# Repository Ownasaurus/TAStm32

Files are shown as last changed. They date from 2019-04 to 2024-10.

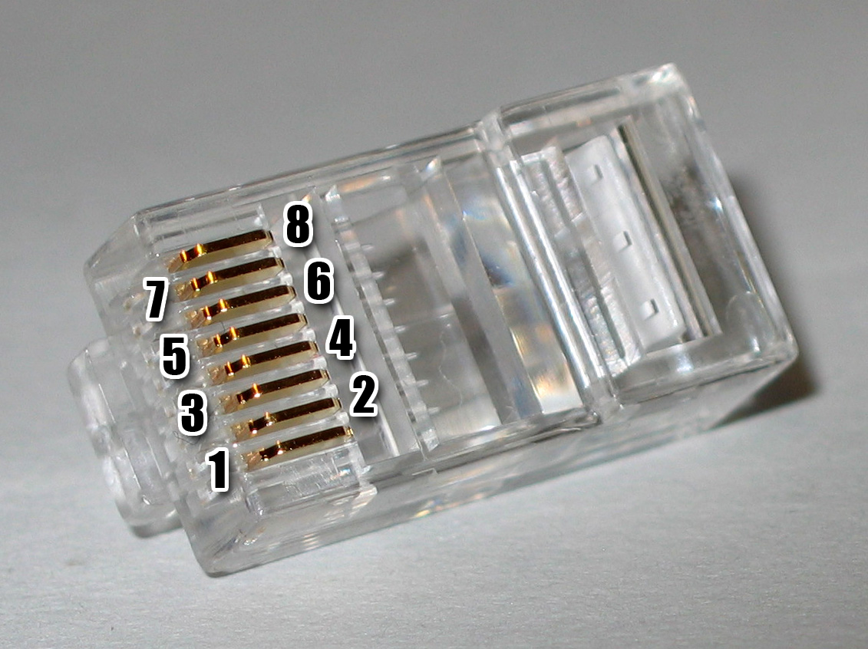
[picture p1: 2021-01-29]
Images/hardware_pinmaps/Rj45plug-8p8c.png

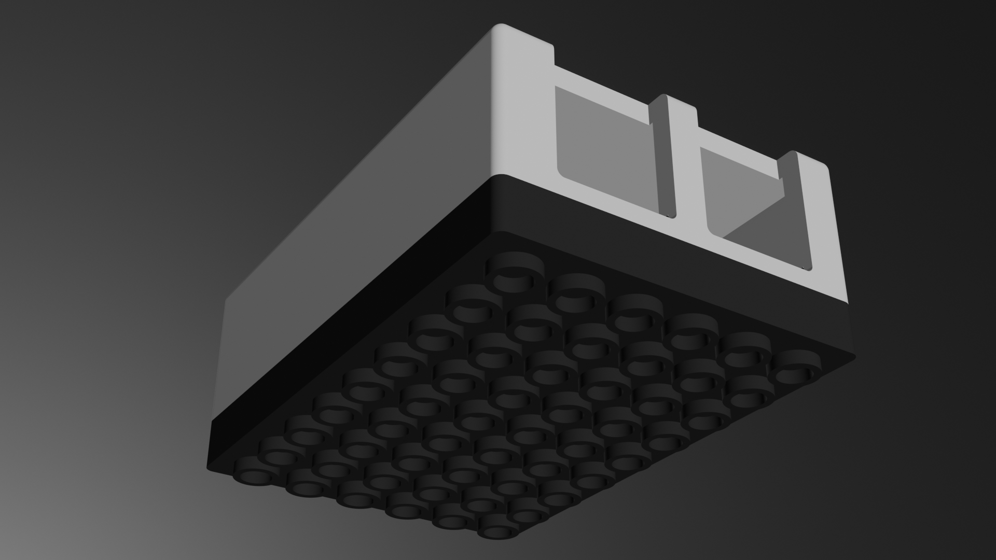
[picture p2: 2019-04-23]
Images/Render2.png

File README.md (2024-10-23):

# TAStm32
Please see the "Projects" section for an overview of the current status of this project!

Please see the "Wiki" section for the technical details of the serial communication protocol!

### Overview

This project aims to create an easy-to-use, multi-system TAS replay device to be used on actual consoles. The name of this project comes from the fact that it is powered by a STM32F4 microcontroller.

## How to use this device

#### Get Python3!
Install the [latest Python 3 release](https://www.python.org/downloads/)

(You may need to log out/log in to refresh the PATH variable)

Then install the required python modules with the following command:

    python3 -m pip install -r python/requirements.txt
    
#### Linux users -- make sure you are in the dialout and plugdev groups!

### Get the python scripts

Download the latest python scripts from https://github.com/Ownasaurus/TAStm32/releases/download/latest/python.zip

### Usage

Dumped TAS movies are available in the [TASBot projects repo](https://github.com/dwangoac/TASBot-Projects/tree/master/replayfiles)

[Scripts to dump your own TASes](https://github.com/dwangoac/TASBot-Projects/blob/master/Dump_Scripts/)

Once you've prepared a movie dump, use it with the TAStm32. Here is one example example is here:

    python3 tastm32.py --console snes --players 1,5 --dpcm --clock 14 --transition 2123 A --blank 1 smb3_agdq.r16m
    
Another option is to use python to run main.py, allowing you to utilize a GUI crated by Zayitskin. You can find more information on his repo here: https://github.com/Zayitskin/TAStm32GUI

## Upgrading firmware 

If it's the first time you're flashing it, short the "DFU" Pins (J13) while plugging tastm32 in.

#### Linux
    apt install dfu-util
OR the equivalent in your distribution. Then run:

    make v3 && make flash

Or :

    make v4 && make flash

#### Windows
1. Install STM32CubeProgrammer
1. Run the tastm32-dfu.py script to put the device in DFU mode (or if it's the first time you're flashing it, short the "DFU" Pins (J13) while plugging tastm32's USB cable into your computer).
1. Use the STM32CubeProgrammer software to flash the latest firmware. The latest firmware can always be found here: https://github.com/Ownasaurus/TAStm32/releases/download/latest/tastm32v3.hex
or
https://github.com/Ownasaurus/TAStm32/releases/download/latest/tastm32v4.hex

## Development (advanced users)

Do you want to fork the codebase and make your own tweaks? Here is some information that may help you.

### Compilation

#### Linux
    apt install gcc-arm-none-eabi binutils-arm-none-eabi libnewlib-arm-none-eabi
OR the equivalent in your distribution. Then run:

    make v3
    
Or : 

    make v4
    
Depending on if you have a v3 or v4 board. (v4 boards were released after July 2021)

#### Windows
1. Install Atollic TrueStudio
1. Right-click on the project > Build Configurations > Set Active, then click "Release v3" or "Release v4" depending on your board version. (v4s came out around July 2021)
1. Project > Build Project and check that the console shows no errors. The last line before "build finished" should be "arm-atollic-eabi-objcopy -O ihex TAStm32.elf TAStm32.hex".
1. Feel free to use the helper scripts "setenv.bat" and either "flashv3.bat" or "flashv4.bat" to assist in flashing firmware. These scripts will work if you have compiled using TrueStudio and if you have STM32CubeProgrammer installed.

### Special Thanks
#### rasteri (@rasteri) - Standalone USB playback, SNES multitap, v4 PCB, and more!
#### TheMas3212 (@TheMas3212) - Aided with all things python, designing the serial communication protocol, helping with PCB design, and debugging throughout the whole process.
#### total (@tewtal) - Helped with NES/SNES protocol and debugging. Provided his code as a reference
#### booto (@booto) - Helped fix N64/GC protocols, serial-over-USB, and debugging
#### Skippy - Pretty much helped a little bit with everything: including software, hardware, advice on proper tools, and more!

dwangoAC (@dwangoac) - warmly accepting me into the TASBot community

micro500 (@micro500) - spent a lot of time teaching me how console replay devices work at a low level

true - for teaching me hardware concepts, helping me choose the perfect MCU for the job, and explaining a lot of low-level things to me

Tien Majerle (@MaJerle) - the owner of https://stm32f4-discovery.net/ helped me with the function which jumps to the DFU bootloader code

CraftedCart - Designed the awesome-looking 3D case

Ilari - for being an extraordinary wealth of knowledge on most topics

Serisium (@serisium) - helped with debugging and PCB design

rcombs (@rcombs) - helped with optimizing the N64 protocol

Sauraen (@sauraen) - Linux setup and installation notes, multiplayer GC/N64 support, misc. GC/N64 improvements

Derf - worked on debugging the genesis protocol together

sspx (@SuperSpyTX) - For help with finding a bug in the N64 controller identity code.

#### If I accidentally forgot to credit you, please let me know so I can fix it!

 - Ownasaurus

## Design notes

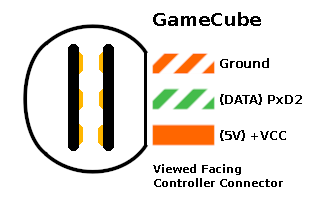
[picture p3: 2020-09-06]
Images/hardware_pinmaps/hardware_gc_v2.png

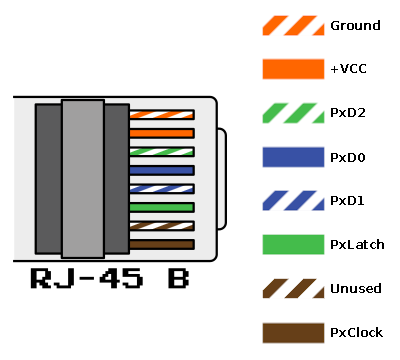
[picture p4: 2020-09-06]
Images/hardware_pinmaps/hardware_rj45_v2.png

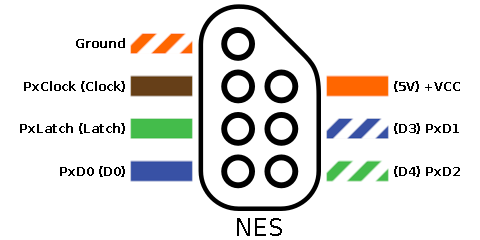
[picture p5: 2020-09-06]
Images/hardware_pinmaps/hardware_nes_v2.png

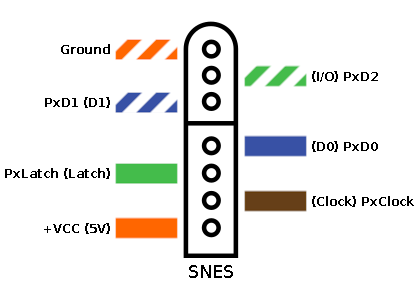
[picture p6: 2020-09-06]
Images/hardware_pinmaps/hardware_snes_v2.png

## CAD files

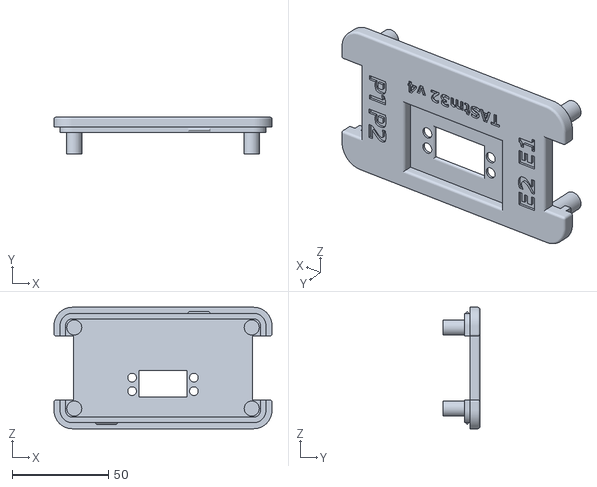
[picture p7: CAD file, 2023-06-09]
PCB and Case/TAStm32 v4r2 Top Case.stl
113.0 x 19.0 x 63.0

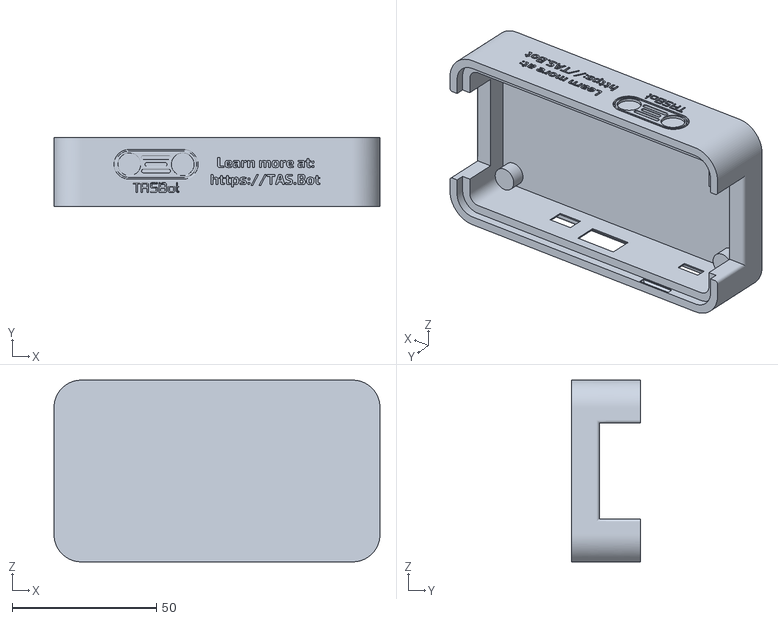
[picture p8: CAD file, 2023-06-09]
PCB and Case/TAStm32 v4r2 Bottom Case.stl
113.0 x 24.0 x 63.0

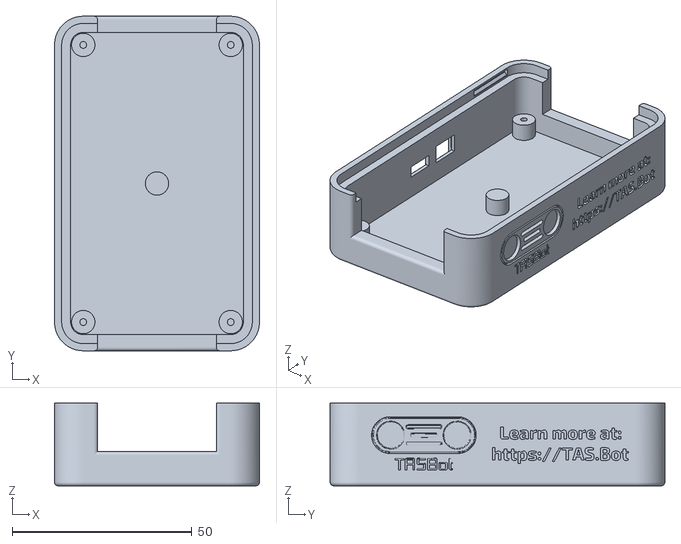
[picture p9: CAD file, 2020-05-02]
PCB and Case/TAStm32 v3 Bottom Case.stl
57.0 x 93.1 x 23.0

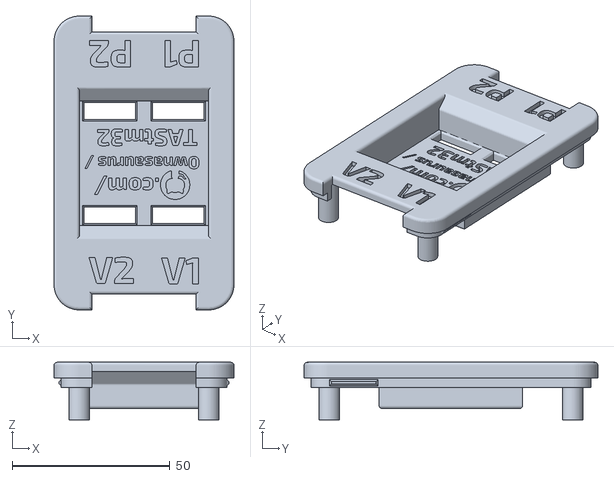
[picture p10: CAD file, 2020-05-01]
PCB and Case/TAStm32 v3 Top Case.stl
57.0 x 93.1 x 18.2

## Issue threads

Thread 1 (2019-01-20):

Consider a computer-less, serial-less implementation where data is read off of a USB stick instead

Ownasaurus, 2019-01-20:
STM32CubeMX does not support OTG mode, where it can be either a host or a device during execution. It would require a bit of manual coding to set up.

Ownasaurus, 2019-11-16:
Going to close this. This kind of feature is likely going to be implemented on @huuf's TASseract with a SD card.

Closed 2019-11-16.

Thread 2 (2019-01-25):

NES replay differs by 1 frame on first execution

Ownasaurus, 2019-01-25:
Title. Have not figured out why, yet.

For the test SMB3 run I am using, 100% of the time it desyncs right before 1-5 on first execution from the time TAStm32 is powered on. But every other run works 100% of the time until I power cycle the board again. Something about the state isn't quite right or isn't being fully reset during a reset. I'm not sure which behavior is "correct" but I want it to be consistent!

Ownasaurus, 2019-01-25:
Fixed in commit e27e4ac0ef27a7a4d680225fe4515a6cbb860ad5

Closed 2019-01-25.

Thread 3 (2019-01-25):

Possibly missing final frame of input

Ownasaurus, 2019-01-25:
Baxter's Tetris TAS runs almost perfectly, but the final name in the score screen ends on "AAXTER" instead of "BAXTER". Suspect there may be an off-by-one error somewhere. Needs further investigation.

Ownasaurus, 2019-01-25:
NVM was a bad dump. New dump correctly ends on "BAXTER"

Closed 2019-01-25.

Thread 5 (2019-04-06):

NES sometimes freezes/errors from poweron

Ownasaurus, 2019-04-06:
Does not occur on NES from reset
Does not occur on SNES from poweron
Does not occur on N64 from poweron

Further investigation required.

Ownasaurus, 2019-04-09:
Resolved in commit 4e1d04dc43595c217e6d137526188c92bfd2c416

Ownasaurus, 2019-04-13:
Still occurs on DwangoAC's toploader. Cannot reproduce on my front(side) loader. Needs further investigation

Ownasaurus, 2019-04-15:
Appears to be resolved by d1cb7327ca6e56d5f5b9ae15ae2e25a618a61e2c. Will re-open if it presents its ugly head again.

Closed 2019-04-15.

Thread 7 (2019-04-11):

occasional static in total snes audio payload

Ownasaurus, 2019-04-11:
-Ofast, very rare but happens

compucat, 2019-04-11:
Notes from stream so they're not forgotten:
Might potentially be fixed by moving vis board update code out of critical interrupt
Disabling optimizations entirely is too slow for audio at all
Potentially look into GCC syntax to explicitly prevent the inline asm from being optimized (instead of getting lucky with moving it into an else clause)

Ownasaurus, 2019-04-15:
Resolved with cca18c4fea3b4b86255974b23f5d309aa6baff13

Ownasaurus, 2019-04-24:
Still occurs, but not commonly. Occurs almost exactly every 1 minute and 22 seconds. Needs further investigation.

Ownasaurus, 2019-04-28:
Actually resolved with 1cd756c9cab559a89cffeb8d6fa63a3e1aff6a26 ;)

Closed 2019-04-28.

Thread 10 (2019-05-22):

Spurious "error during reset" at random

compucat, 2019-05-22:
Sometimes after killing a run, tastm32.py will return "error during reset" repeatedly until you either (a) get lucky or (b) powercycle the hardware. dwangoAC duplicated the issue on stream by accident. Probably just an edge case in the comms between tastm32 and the python script

Ownasaurus, 2019-05-22:
Do you know if he had updated to the latest version?

compucat, 2019-05-22:
Not certain, but I experienced it on latest myself.

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

Ownasaurus, 2019-05-22:
The function to process serial packets is a state machine which processes one byte at a time and keeps track of its state. It was done this way just in case the serial data packets were split at an unexpected location.
The reported problem would probably occur if input ends unexpectedly. One potential solution would be to have a "timeout/reset" period of say... 0.5 seconds where if input stops, it should reset its state to being ready for a new serial command. This could be implemented either by counting cycles or using a hardware timer with interrupts. Feel free to implement this yourself if you'd like. If not, I can hopefully get to it in the near future.

compucat, 2019-05-22:
I'll write a quick patch, but I won't have hardware to test on until I return from travel.

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

Ownasaurus, 2019-06-25:
A similar or related error: COM port in use occurs seemingly randomly between runs

Closed 2019-07-04.

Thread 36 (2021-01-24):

Soft Reset Transitions broken at HEAD 165a556666a038a09f581ebf392f1f8c8422c087

TheMas3212, 2021-01-24:
Test case Super Mario World 96 exit WIP requires a soft reset at frame 1117 (r16m can be provided via dm)
this works on commit 372cd6142d27206ca348e56b181491f0794b47e8 with the command:
`./tastm32.py --console snes --players 1,2,5,6 --blank 0 --softreset --transition 1117 S 96wip.r16m`
however it fails on HEAD at 165a556666a038a09f581ebf392f1f8c8422c087
and on 8335dce6078db1fd34c518df924a76e776369c17
trying the `--nobulk` flag at the suggestion of @Ownasaurus did not help

normally works with a reset on frame 1117, fails to create the save unless reset is at 1135
save is created with the reset at 1135 however it drops a number of inputs and gets stuck at the following title screen

Ownasaurus, 2021-01-25:
Upon further investigation, it appears that the reset pin was originally switched to push-pull so the pin would work with a power replay. It also works with the consoles well enough -- or so we thought. I guess it throws off tight timing resets. Need some time to consider our options. The power replay control won't work anymore if we make it OD again.

The best solution I've thought of thus far is to revert back to OD to restore NES/SNES power functionality... then add an external pullup to my my power relay circuit to allow it to still function. Hope to make a decision to resolve this soon.

Ownasaurus, 2021-01-25:
Of interest is the fact that analogic logic analysis shows that the pins goes from high to low and vice versa in about 100ns in either case. However, in PP mode, the pin is held at 3v3 instead of its suspected 5v. While this still works, it may be doing some funky things to the console, ruining timings and possibly more.

Ownasaurus, 2021-01-27:
Resolved in commit 16e3e23

Closed 2021-01-27.

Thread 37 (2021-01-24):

Feature request: Ping command

Ownasaurus, 2021-01-24:
Feature requested by ViGrey

compucat, 2021-01-27:
I wrote a stm32 side implementation and tested on-device; PR'ing into Mas's branch (#41) before PR'ing from there to master.

Closed 2021-01-28.

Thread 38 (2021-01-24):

Move recent master commit to a dev branch

Ownasaurus, 2021-01-24:
I should not have committed the software latch glitch filtering to master last week. Should move to dev branch and test further before committing to master. Also this should be resolved by hardware buffers in v4

Ownasaurus, 2021-01-24:
Reverted corresponding commits. Opted not to commit to a separate branch at this time.

Closed 2021-01-24.

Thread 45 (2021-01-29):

Case Modification Suggestion - Make top fit only when aligned correctly

ViGrey, 2021-01-29:
The top of the case for v3 of the TAStm32 has a special markings to indicate P1, P2, V1, and V2, making the top 1-way, but the case can still be closed even if the top of the case is rotated 180 degrees.

I personally suggest placing a notch on one side of the top part of the case and a bump that fits into the notch on the bottom part of the case so the case can only be closed correctly.

Ownasaurus, 2021-07-09:
Just a status update so you know I didn't forget about you -- a test candidate for the version 4 case is being printed as we speak, The new (albeit similar) design can no longer be accidentally put together backwards.

Ownasaurus, 2021-07-12:
Since v4 has a screen and buttons which are not centered on the PCB, the new top half of the case will only fit on one way.

Ownasaurus, 2021-07-13:
Will be resolved by #57

Ownasaurus, 2021-07-23:
Resolved by #57.

Closed 2021-07-23.

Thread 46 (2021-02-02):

Manual Merge: 2+ player support for gc/n64

Ownasaurus, 2021-02-02:
I would like to manually merge https://github.com/sauraen/TAStm32/tree/FourPlayerGCN64. It is probably easier to manually merge in the changes rather than do a proper pull request due to the deviation over time. Careful consideration should be made as to whether or not players 3 and 4 can be supported in the upcoming v4 hardware changes. Since for vis boards, voltage is an output, but for N64, it would not be. Either way, 2-player support should be easy peasy! Just gotta do it. Since it's not going to be a formal pull request, need to make sure to update README.md to properly credit Sauraen

Ownasaurus, 2021-02-15:
Began to resolve this issue in: https://github.com/Ownasaurus/TAStm32/tree/n64-2p . Decided to make it only 2p for now.

Ownasaurus, 2021-02-27:
Confirmed NES and SNES are still functioning correctly

Ownasaurus, 2021-02-28:
Done

Closed 2021-02-28.

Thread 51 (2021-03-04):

PCB v4 -- including many new features!

Ownasaurus, 2021-03-04:
Planned new features:

- Screen
- Load runs from USB stick
- improved signal integrity with buffer chips

Ownasaurus, 2021-06-07:
Will be resolved by #57

Ownasaurus, 2021-07-23:
Resolved by #57.

Closed 2021-07-23.

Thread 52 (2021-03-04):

Merge in and document special GCN code

Ownasaurus, 2021-03-04:
Things to either merge to master or at least clean up and keep in its own branch:

- A/V signal processing code
- Rumble processing and sync code

Ownasaurus, 2021-06-03:
rumble processing and sync code has been merged in. still need to document how to sync a melee run. a/v signal processing code will remain separate in rasteri's ADCtest branch since it is currently unused.

Ownasaurus, 2021-06-04:
ADCtest branch now migrated to origin (this repo)
TODO: upload melee preprocessing script and document procedure

Ownasaurus, 2021-07-10:
Resolved with 2d18f01 and wiki page

Closed 2021-07-10.

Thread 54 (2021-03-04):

Add relayreset command

Ownasaurus, 2021-03-04:
It would be another power command, like softreset and hardreset. The aforementioned commands operate on open-drain to avoid having strange console side effects. However, to work with a power relay strip, the reset pin should operate on push-pull. Therefore,  a new command should be added to the protocol, firmware, and python driver.

Ownasaurus, 2021-07-09:
Resolved in #58

Closed 2021-07-09.

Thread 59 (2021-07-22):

Compartmentalized Expansions and Terminology

SuperDragonite2172, 2021-07-22:
A plan for how to expand the TAStm32's functionality and provide easy-to-understand terminology for the components.  The terminology could also apply to other replay devices depending on acceptance.

### Input Replay Device
The main TAStm32 board which focuses on replaying inputs to the console like it currently does.

### Input Capture Device
A separate board that connects to one of the exports to capture and save live input (suggested originally by dwangoAC).

### Input Display Device
Another separate board connected via export that allows for detailed input display and potentially other information such as authors of the currently playing replay, commentary, etc. (Extra information up for further discussion)

Ownasaurus, 2025-04-07:
I'm going to close this because I'm not sure how to resolve this. These are good ideas but are likely outside the scope of the TAStm32. It can be re-opened if other people do end up making new separate boards such as capture devices.

Closed 2025-04-07.

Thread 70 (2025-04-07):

Erroneous Start press?

Ownasaurus, 2025-04-07:
Years ago, DwangoAC reported occasions where there was an extra start press at the beginning of a replay. Perhaps on the first frame? Perhaps it was when the console was already on while a reply was loaded? Ideally, someone could reproduce this and fix it.

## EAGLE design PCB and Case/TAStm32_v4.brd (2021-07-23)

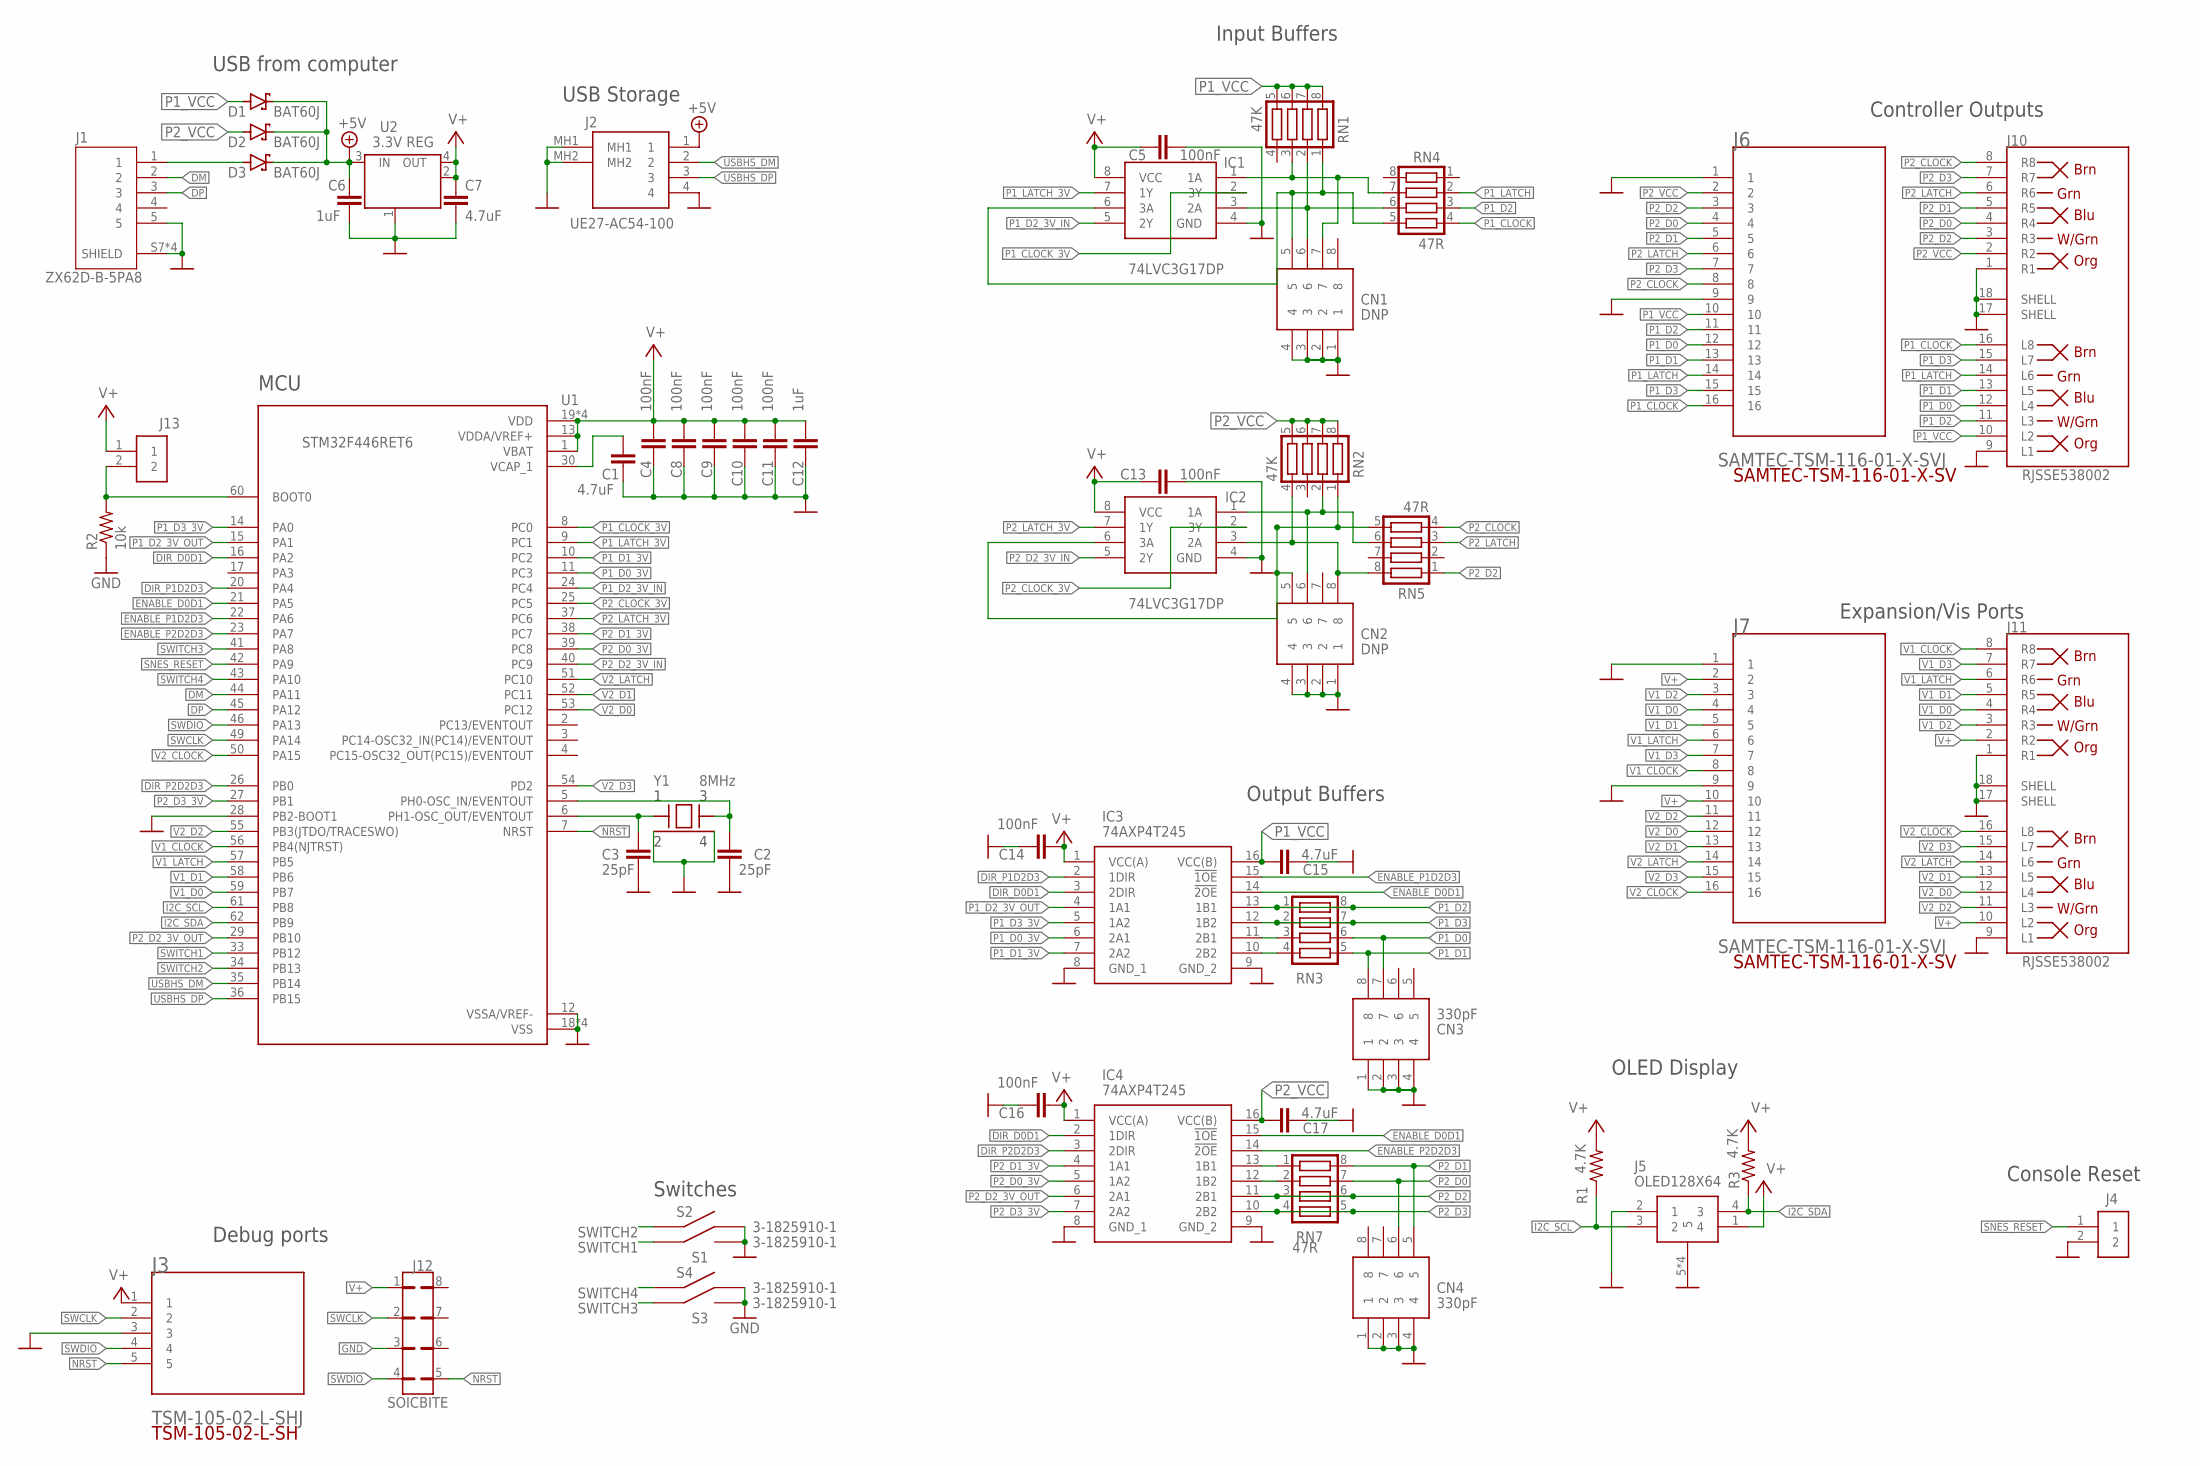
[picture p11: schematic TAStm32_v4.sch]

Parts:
C1, C7, C15, C17: 4.7uF; C0603K
C2, C3: 25pF; C0603K
C4, C5, C8, C9, C10, C11, C13, C14, C16: 100nF; C0603K
C6, C12: 1uF; C0603K
CN1, CN2: DNP; CA0612KRX7R7BB104
CN3, CN4: 330pF; CA0612KRX7R7BB104
D1, D2, D3: BAT60J; DIODE_SOD323_ST
IC1, IC2: 74LVC3G17DP; SOP65P400X110-8N
IC3, IC4: 74AXP4T245; SOP65P640X110-16N
J1: ZX62D-B-5PA8; HIROSE_ZX62D-B-5PA8
J2: UE27-AC54-100; UE27AC54100
J3: TSM-105-02-L-SHJ; TSM-105-02-L-SH
J4, J13: CONSOLE_RESET; SAMTEC-TSM-102-01-X-SH
J5: OLED128X64; OLED
J6, J7: SAMTEC-TSM-116-01-X-SVJ; SAMTEC-TSM-116-01-X-SV
J10, J11: RJSSE538002; AMPHENOL_RJSSE538002
J12: SOICBITE
R1, R3: 4.7K; R0805
R2: 10k; R0805
RN1, RN2: 47K; CTS742C083
RN3: CTS742C083
RN4, RN5, RN7: 47R; CTS742C083
S1, S2, S3, S4: 3-1825910-1; 3-1825910-1_318259101
U1: STM32F446RET6; QFP50P1200X1200X160-64N
U2: 3.3V REG; SOT223
Y1: 8MHz; DFN-4

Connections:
+5V: C6.2, D1.C, D2.C, D3.C, J2.1, U2.3 (IN)
BOOT0: J13.2, R2.2, U1.60 (BOOT0)
DIR_D0D1: IC3.3 (2DIR), IC4.2 (1DIR), U1.16 (PA2)
DIR_P1D2D3: IC3.2 (1DIR), U1.20 (PA4)
DIR_P2D2D3: IC4.3 (2DIR), U1.26 (PB0)
DM: J1.2, U1.44 (PA11)
DP: J1.3, U1.45 (PA12)
ENABLE_D0D1: IC3.14 (!2OE), IC4.15 (!1OE), U1.21 (PA5)
ENABLE_P1D2D3: IC3.15 (!1OE), U1.22 (PA6)
ENABLE_P2D2D3: IC4.14 (!2OE), U1.23 (PA7)
GND: C1.2, C2.1, C3.1, C4.1, C5.2, C6.1, C7.1, C8.1, C9.1, C10.1, C11.1, C12.1, C13.2, C14.1, C15.2, C16.1, C17.2, CN1.1, CN1.2, CN1.3, CN1.4, CN2.1, CN2.2, CN2.3, CN2.4, CN3.1, CN3.2, CN3.3, CN3.4, CN4.1, CN4.2, CN4.3, CN4.4, IC1.4 (GND), IC2.4 (GND), IC3.8 (GND_1), IC3.9 (GND_2), IC4.8 (GND_1), IC4.9 (GND_2), J1.5, J1.S7 (SHIELD), J1.S8 (SHIELD), J1.S9 (SHIELD), J1.S10 (SHIELD), J2.4, J2.MH1, J2.MH2, J3.3, J4.2, J5.2 (1), J5.5, J5.6 (5), J5.7 (5), J5.8 (5), J6.1, J6.9, J7.1, J7.9, J10.1 (R1), J10.9 (L1), J10.17 (SHELL), J10.18 (SHELL), J11.1 (R1), J11.9 (L1), J11.17 (SHELL), J11.18 (SHELL), J12.3, R2.1, S1.3, S1.4, S2.3, S2.4, S3.3, S3.4, S4.3, S4.4, U1.12 (VSSA/VREF-), U1.18 (VSS), U1.28 (PB2-BOOT1), U1.31 (VSS), U1.47 (VSS), U1.63 (VSS), U2.1 (GND/ADJ), Y1.2, Y1.4
I2C_SCL: J5.3 (2), R1.1, U1.61 (PB8)
I2C_SDA: J5.4 (3), R3.1, U1.62 (PB9)
unnamed: D3.A, J1.1
unnamed: CN2.6, IC2.1 (1A), RN2.2, RN5.6
unnamed: C3.2, U1.6 (PH1-OSC_OUT/EVENTOUT), Y1.1
unnamed: CN2.5, IC2.6 (3A), RN2.1, RN5.5
unnamed: CN2.8, IC2.3 (2A), RN2.4, RN5.8
unnamed: IC3.11 (2B1), RN3.3
unnamed: IC3.10 (2B2), RN3.4
unnamed: IC4.12 (1B2), RN7.2
unnamed: IC4.13 (1B1), RN7.1
unnamed: CN1.7, IC1.1 (1A), RN1.3, RN4.7
unnamed: CN1.5, IC1.6 (3A), RN1.1, RN4.5
unnamed: CN1.6, IC1.3 (2A), RN1.2, RN4.6
NRST: J3.5, J12.5, U1.7 (NRST)
P1_CLOCK: J6.16, J10.16 (L8), RN4.4
P1_CLOCK_3V: IC1.2 (3Y), U1.8 (PC0)
P1_D0: CN3.7, J6.12, J10.12 (L4), RN3.6
P1_D0_3V: IC3.6 (2A1), U1.11 (PC3)
P1_D1: CN3.8, J6.13, J10.13 (L5), RN3.5
P1_D1_3V: IC3.7 (2A2), U1.10 (PC2)
P1_D2: IC3.13 (1B1), J6.11, J10.11 (L3), RN3.1, RN3.8, RN4.3
P1_D2_3V_IN: IC1.5 (2Y), U1.24 (PC4)
P1_D2_3V_OUT: IC3.4 (1A1), U1.15 (PA1)
P1_D3: IC3.12 (1B2), J6.15, J10.15 (L7), RN3.2, RN3.7
P1_D3_3V: IC3.5 (1A2), U1.14 (PA0)
P1_LATCH: J6.14, J10.14 (L6), RN4.2
P1_LATCH_3V: IC1.7 (1Y), U1.9 (PC1)
P1_VCC: C15.1, D1.A, IC3.16 (VCC(B)), J6.10, J10.10 (L2), RN1.5, RN1.6, RN1.7, RN1.8
P2_CLOCK: J6.8, J10.8 (R8), RN5.4
P2_CLOCK_3V: IC2.2 (3Y), U1.25 (PC5)
P2_D0: CN4.6, J6.4, J10.4 (R4), RN7.7
P2_D0_3V: IC4.5 (1A2), U1.39 (PC8)
P2_D1: CN4.5, J6.5, J10.5 (R5), RN7.8
P2_D1_3V: IC4.4 (1A1), U1.38 (PC7)
P2_D2: IC4.11 (2B1), J6.3, J10.3 (R3), RN5.1, RN7.3, RN7.6
P2_D2_3V_IN: IC2.5 (2Y), U1.40 (PC9)
P2_D2_3V_OUT: IC4.6 (2A1), U1.29 (PB10)
P2_D3: IC4.10 (2B2), J6.7, J10.7 (R7), RN7.4, RN7.5
P2_D3_3V: IC4.7 (2A2), U1.27 (PB1)
P2_LATCH: J6.6, J10.6 (R6), RN5.3
P2_LATCH_3V: IC2.7 (1Y), U1.37 (PC6)
P2_VCC: C17.1, D2.A, IC4.16 (VCC(B)), J6.2, J10.2 (R2), RN2.5, RN2.6, RN2.7, RN2.8
SNES_RESET: J4.1, U1.42 (PA9)
SWCLK: J3.2, J12.2, U1.49 (PA14)
SWDIO: J3.4, J12.4, U1.46 (PA13)
SWITCH1: S1.1, S1.2, U1.33 (PB12)
SWITCH2: S2.1, S2.2, U1.34 (PB13)
SWITCH3: S3.1, S3.2, U1.41 (PA8)
SWITCH4: S4.1, S4.2, U1.43 (PA10)
USBHS_DM: J2.2, U1.35 (PB14)
USBHS_DP: J2.3, U1.36 (PB15)
V1_CLOCK: J7.8, J11.8 (R8), U1.56 (PB4(NJTRST))
V1_D0: J7.4, J11.4 (R4), U1.59 (PB7)
V1_D1: J7.5, J11.5 (R5), U1.58 (PB6)
V1_D2: J7.3, J11.3 (R3)
V1_D3: J7.7, J11.7 (R7)
V1_LATCH: J7.6, J11.6 (R6), U1.57 (PB5)
V2_CLOCK: J7.16, J11.16 (L8), U1.50 (PA15)
V2_D0: J7.12, J11.12 (L4), U1.53 (PC12)
V2_D1: J7.13, J11.13 (L5), U1.52 (PC11)
V2_D2: J7.11, J11.11 (L3), U1.55 (PB3(JTDO/TRACESWO))
V2_D3: J7.15, J11.15 (L7), U1.54 (PD2)
V2_LATCH: J7.14, J11.14 (L6), U1.51 (PC10)
V+: C4.2, C5.1, C7.2, C8.2, C9.2, C10.2, C11.2, C12.2, C13.1, C14.2, C16.2, IC1.8 (VCC), IC2.8 (VCC), IC3.1 (VCC(A)), IC4.1 (VCC(A)), J3.1, J5.1 (4), J7.2, J7.10, J11.2 (R2), J11.10 (L2), J12.1, J13.1, R1.2, R3.2, U1.1 (VBAT), U1.13 (VDDA/VREF+), U1.19 (VDD), U1.32 (VDD), U1.48 (VDD), U1.64 (VDD), U2.2 (OUT), U2.4 (OUT)
VCAP: C1.1, U1.30 (VCAP_1)
XTAL1: C2.2, U1.5 (PH0-OSC_IN/EVENTOUT), Y1.3

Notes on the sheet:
USB from computer
USB Storage
MCU
Debug ports
OLED Display
Console Reset
Controller Outputs
Expansion/Vis Ports
Input Buffers
Output Buffers
Switches

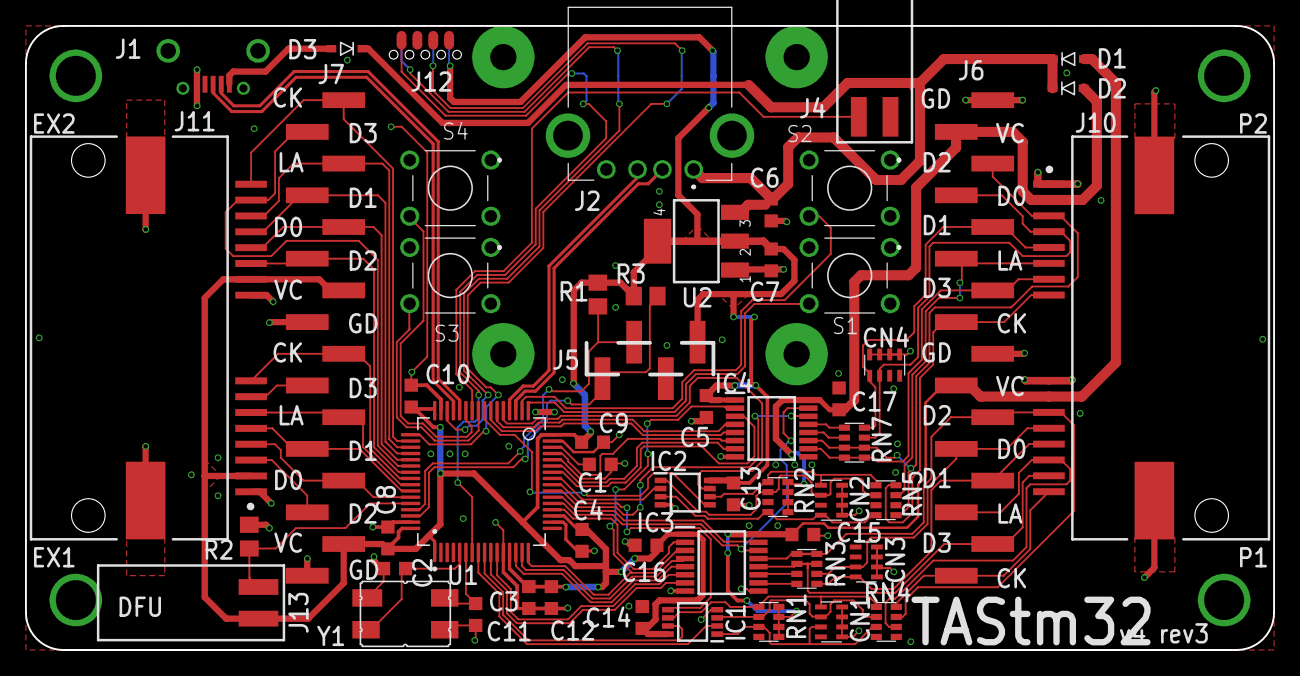
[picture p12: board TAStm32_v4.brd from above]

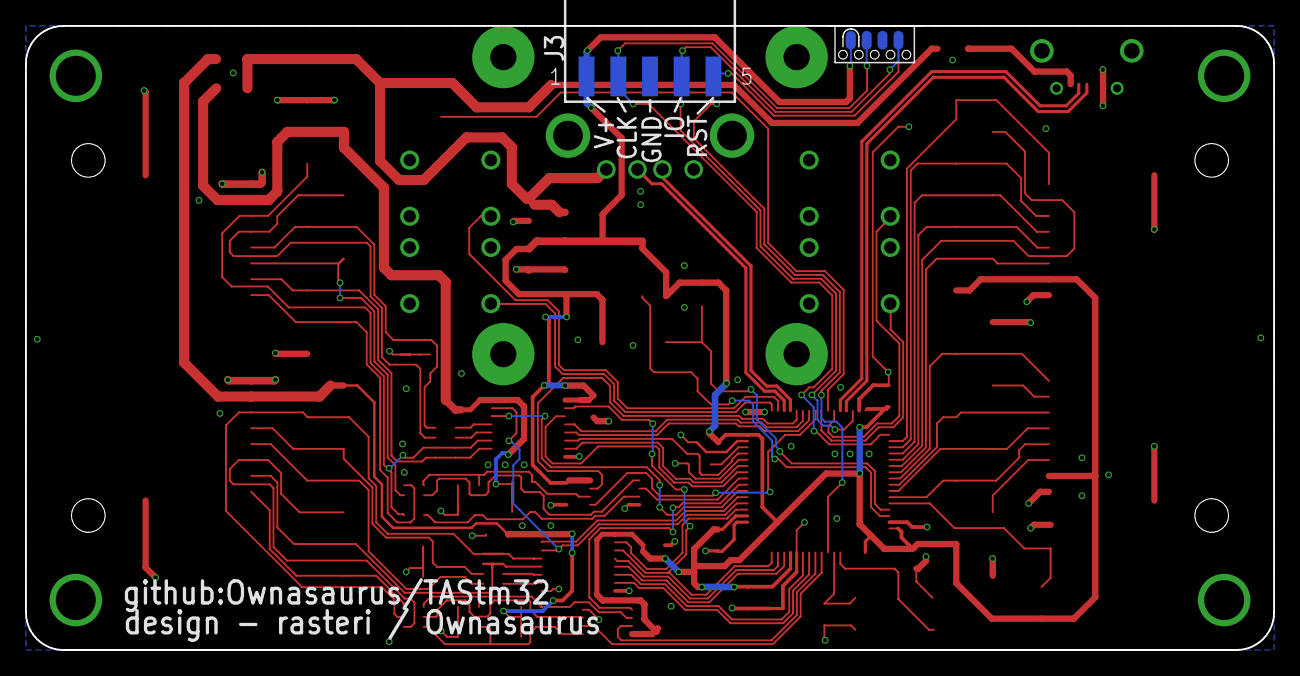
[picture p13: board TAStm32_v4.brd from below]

Board: 2 copper layers, 100.0 x 50.0 mm, 55 parts (2 on the bottom side), 78 nets.

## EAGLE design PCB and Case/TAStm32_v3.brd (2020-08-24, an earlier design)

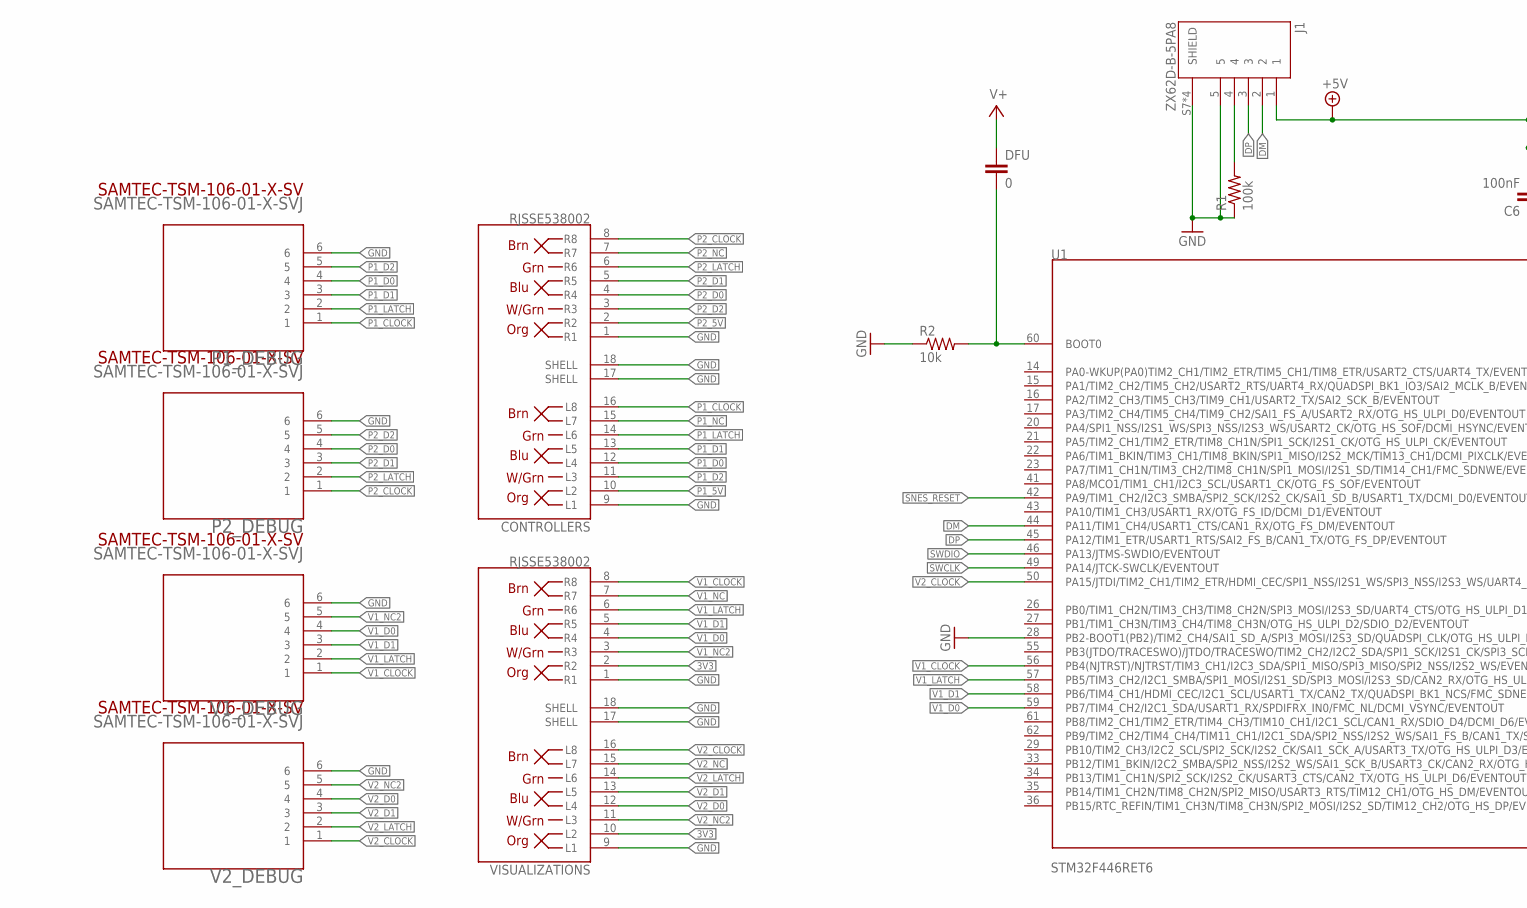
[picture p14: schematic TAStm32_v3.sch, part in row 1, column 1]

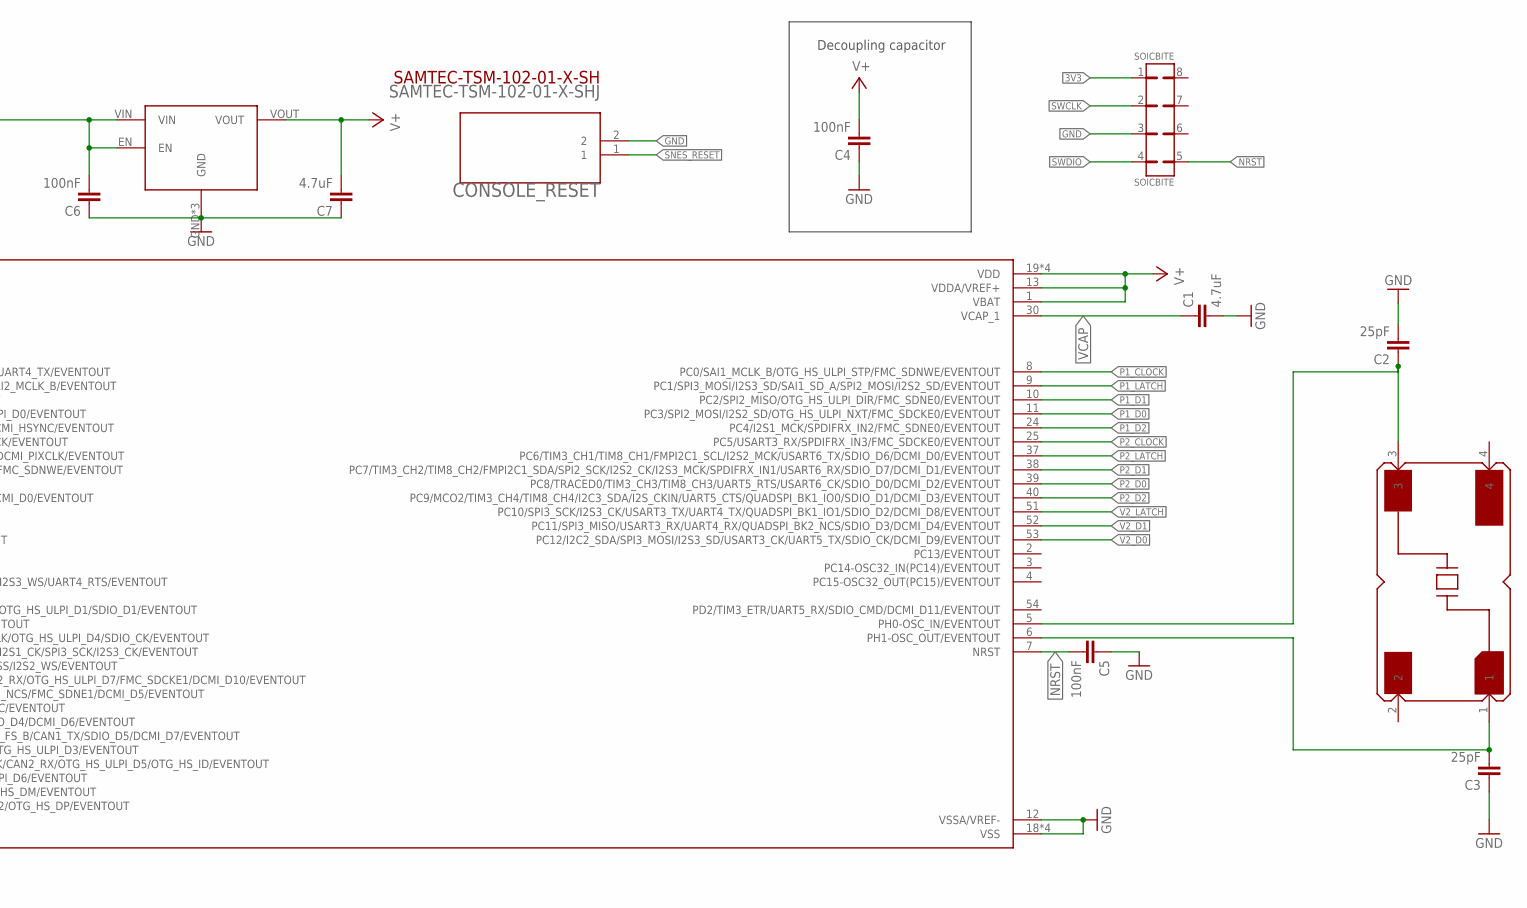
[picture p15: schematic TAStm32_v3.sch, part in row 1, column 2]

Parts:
C1, C7: 4.7uF; C0805K
C2, C3: 25pF; C0805K
C4, C5, C6: 100nF; C0805K
CONSOLE_RESET: SAMTEC-TSM-102-01-X-SHJ; SAMTEC-TSM-102-01-X-SH
CONTROLLERS: RJSSE538002; AMPHENOL_RJSSE538002
DFU: 0; C0603
J1: ZX62D-B-5PA8; HIROSE_ZX62D-B-5PA8
P1_DEBUG, P2_DEBUG: SAMTEC-TSM-106-01-X-SVJ; SAMTEC-TSM-106-01-X-SV
R1: 100k; R0805
R2: 10k; R0805
SOICBITE: SOICBITE
U1: STM32F446RET6; QFP50P1200X1200X160-64N
V1_DEBUG, V2_DEBUG: SAMTEC-TSM-106-01-X-SVJ; SAMTEC-TSM-106-01-X-SV
VISUALIZATIONS: RJSSE538002; AMPHENOL_RJSSE538002
V_REG: S-1172B33-U5T1G
XTAL: ABMM-8.000MHZ-B2-T; DFN-4

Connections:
3V3: C4.2, C7.2, DFU.1, SOICBITE.1, U1.1 (VBAT), U1.13 (VDDA/VREF+), U1.19 (VDD), U1.32 (VDD), U1.48 (VDD), U1.64 (VDD), VISUALIZATIONS.2 (R2), VISUALIZATIONS.10 (L2), V_REG.VOUT
+5V: C6.2, J1.1, V_REG.EN, V_REG.VIN
BOOT0: DFU.2, R2.2, U1.60 (BOOT0)
DM: J1.2, U1.44 (PA11/TIM1_CH4/USART1_CTS/CAN1_RX/OTG_FS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)
DP: J1.3, U1.45 (PA12/TIM1_ETR/USART1_RTS/SAI2_FS_B/CAN1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)
GND: C1.2, C2.2, C3.1, C4.1, C5.1, C6.1, C7.1, CONSOLE_RESET.2, CONTROLLERS.1 (R1), CONTROLLERS.9 (L1), CONTROLLERS.17 (SHELL), CONTROLLERS.18 (SHELL), J1.5, J1.S7 (SHIELD), J1.S8 (SHIELD), J1.S9 (SHIELD), J1.S10 (SHIELD), P1_DEBUG.6, P2_DEBUG.6, R1.1, R2.1, SOICBITE.3, U1.12 (VSSA/VREF-), U1.18 (VSS), U1.28 (PB2-BOOT1(PB2)/TIM2_CH4/SAI1_SD_A/SPI3_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), U1.31 (VSS), U1.47 (VSS), U1.63 (VSS), V1_DEBUG.6, V2_DEBUG.6, VISUALIZATIONS.1 (R1), VISUALIZATIONS.9 (L1), VISUALIZATIONS.17 (SHELL), VISUALIZATIONS.18 (SHELL), V_REG.GND, V_REG.GND2 (GND), V_REG.GND3 (GND)
ID: J1.4, R1.2
NRST: C5.2, SOICBITE.5, U1.7 (NRST)
P1_5V: CONTROLLERS.10 (L2)
P1_CLOCK: CONTROLLERS.16 (L8), P1_DEBUG.1, U1.8 (PC0/SAI1_MCLK_B/OTG_HS_ULPI_STP/FMC_SDN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)
P1_D0: CONTROLLERS.12 (L4), P1_DEBUG.4, U1.11 (PC3/SPI2_MOSI/I2S2_SD/OTG_HS_ULPI_NXT/F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)
P1_D1: CONTROLLERS.13 (L5), P1_DEBUG.3, U1.10 (PC2/SPI2_MISO/OTG_HS_ULPI_DIR/FMC_SDNE0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)
P1_D2: CONTROLLERS.11 (L3), P1_DEBUG.5, U1.24 (PC4/I2S1_MCK/SPDIFRX_IN2/FMC_SDNE0/EVEN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)
P1_LATCH: CONTROLLERS.14 (L6), P1_DEBUG.2, U1.9 (PC1/SPI3_MOSI/I2S3_SD/SAI1_SD_A/SPI2_MO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)
P1_NC: CONTROLLERS.15 (L7)
P2_5V: CONTROLLERS.2 (R2)
P2_CLOCK: CONTROLLERS.8 (R8), P2_DEBUG.1, U1.25 (PC5/USART3_RX/SPDIFRX_IN3/FMC_SDCKE0/EV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)
P2_D0: CONTROLLERS.4 (R4), P2_DEBUG.4, U1.39 (PC8/TRACED0/TIM3_CH3/TIM8_CH3/UART5_RTS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)
P2_D1: CONTROLLERS.5 (R5), P2_DEBUG.3, U1.38 (PC7/TIM3_CH2/TIM8_CH2/FMPI2C1_SDA/SPI2_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)
P2_D2: CONTROLLERS.3 (R3), P2_DEBUG.5, U1.40 (PC9/MCO2/TIM3_CH4/TIM8_CH4/I2C3_SDA/I2S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)
P2_LATCH: CONTROLLERS.6 (R6), P2_DEBUG.2, U1.37 (PC6/TIM3_CH1/TIM8_CH1/FMPI2C1_SCL/I2S2_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)
P2_NC: CONTROLLERS.7 (R7)
SNES_RESET: CONSOLE_RESET.1, U1.42 (PA9/TIM1_CH2/I2C3_SMBA/SPI2_SCK/I2S2_CK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)
SWCLK: SOICBITE.2, U1.49 (PA14/JTCK-SWCLK/EVENTOUT)
SWDIO: SOICBITE.4, U1.46 (PA13/JTMS-SWDIO/EVENTOUT)
V1_CLOCK: U1.56 (PB4(NJTRST)/NJTRST/TIM3_CH1/I2C3_SDA/SP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), V1_DEBUG.1, VISUALIZATIONS.8 (R8)
V1_D0: U1.59 (PB7/TIM4_CH2/I2C1_SDA/USART1_RX/SPDIFRX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), V1_DEBUG.4, VISUALIZATIONS.4 (R4)
V1_D1: U1.58 (PB6/TIM4_CH1/HDMI_CEC/I2C1_SCL/USART1_T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), V1_DEBUG.3, VISUALIZATIONS.5 (R5)
V1_LATCH: U1.57 (PB5/TIM3_CH2/I2C1_SMBA/SPI1_MOSI/I2S1_S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), V1_DEBUG.2, VISUALIZATIONS.6 (R6)
V1_NC: VISUALIZATIONS.7 (R7)
V1_NC2: V1_DEBUG.5, VISUALIZATIONS.3 (R3)
V2_CLOCK: U1.50 (PA15/JTDI/TIM2_CH1/TIM2_ETR/HDMI_CEC/SP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), V2_DEBUG.1, VISUALIZATIONS.16 (L8)
V2_D0: U1.53 (PC12/I2C2_SDA/SPI3_MOSI/I2S3_SD/USART3_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), V2_DEBUG.4, VISUALIZATIONS.12 (L4)
V2_D1: U1.52 (PC11/SPI3_MISO/USART3_RX/UART4_RX/QUADS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), V2_DEBUG.3, VISUALIZATIONS.13 (L5)
V2_LATCH: U1.51 (PC10/SPI3_SCK/I2S3_CK/USART3_TX/UART4_T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), V2_DEBUG.2, VISUALIZATIONS.14 (L6)
V2_NC: VISUALIZATIONS.15 (L7)
V2_NC2: V2_DEBUG.5, VISUALIZATIONS.11 (L3)
VCAP: C1.1, U1.30 (VCAP_1)
XTAL1: C2.1, U1.5 (PH0-OSC_IN/EVENTOUT), XTAL.3
XTAL2: C3.2, U1.6 (PH1-OSC_OUT/EVENTOUT), XTAL.1

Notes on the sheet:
Decoupling capacitor

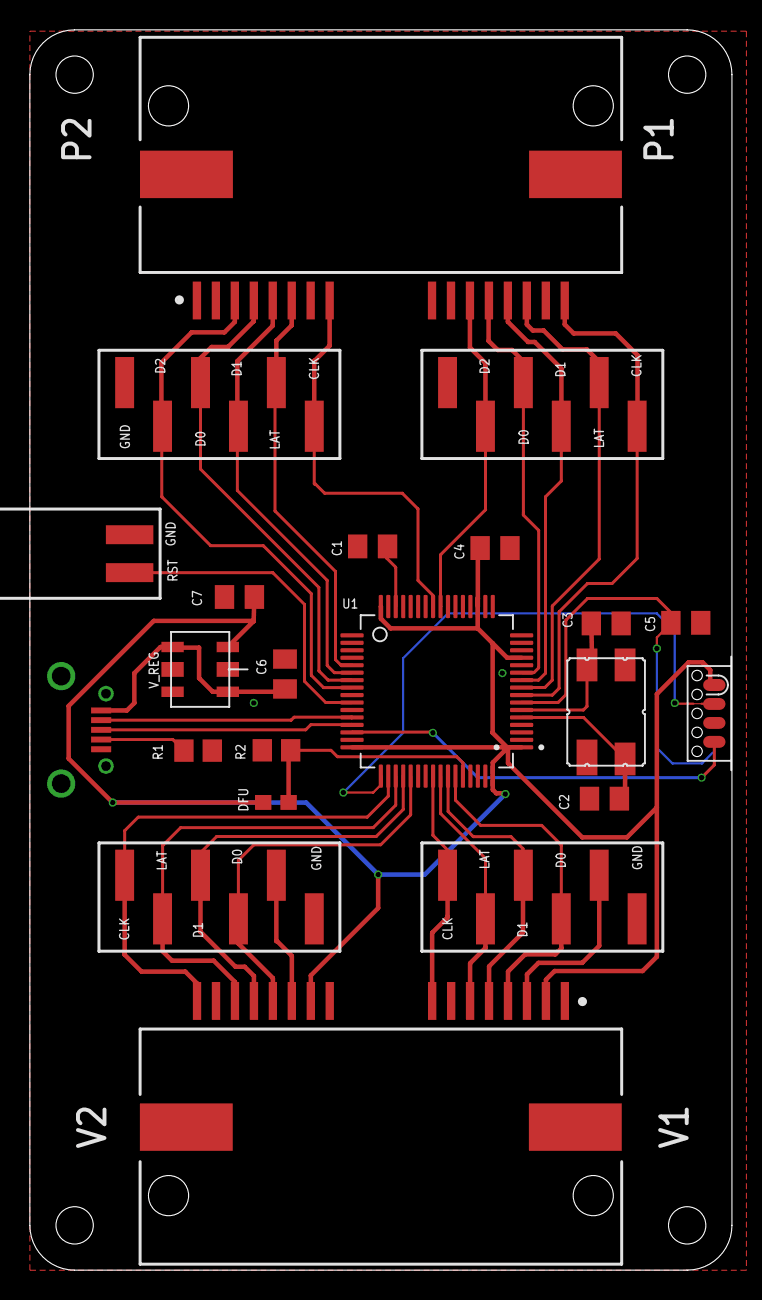
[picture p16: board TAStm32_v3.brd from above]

Board: 2 copper layers, 47.0 x 83.1 mm, 22 parts (0 on the bottom side), 34 nets.

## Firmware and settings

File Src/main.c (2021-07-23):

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

/* Includes ------------------------------------------------------------------*/
#include "main.h"
#include "fatfs.h"
#include "usb_device.h"
#include "usb_host.h"

/* USER CODE BEGIN Includes */
#include <string.h>
#include "usbd_cdc_if.h"
#include "n64.h"
#include "TASRun.h"
#include "stm32f4xx_it.h"
#include "serial_interface.h"
#include "usbplayback/usbplayback.h"
/* USER CODE END Includes */

I2C_HandleTypeDef hi2c1;

TIM_HandleTypeDef htim2;
TIM_HandleTypeDef htim3;
TIM_HandleTypeDef htim6;
TIM_HandleTypeDef htim7;
TIM_HandleTypeDef htim10;

/* USER CODE BEGIN PV */
volatile uint8_t jumpToDFU;
/* USER CODE END PV */

void SystemClock_Config(void);
static void MX_TIM3_Init(void);
static void MX_TIM6_Init(void);
static void MX_TIM7_Init(void);
static void MX_TIM10_Init(void);
static void MX_I2C1_Init(void);
static void MX_TIM2_Init(void);
void MX_USB_HOST_Process(void);

/* USER CODE BEGIN PFP */

// Reset GPIO back to poweron state

/* USER CODE END PFP */

/**
  * @brief  The application entry point.
  * @retval int
  */
int main(void)
{
  /* USER CODE BEGIN 1 */
	// Specifies whether the OLED screen has been detected and therefore whether or not to send data to it

	uint8_t screenOK = 0;
  /* USER CODE END 1 */

  /* MCU Configuration--------------------------------------------------------*/

  /* Reset of all peripherals, Initializes the Flash interface and the Systick. */
  HAL_Init();

  /* Configure the system clock */
  SystemClock_Config();

  /* USER CODE BEGIN SysInit */
  serial_interface_reset();
  ResetGPIO();
  /* USER CODE END SysInit */

  /* Initialize all configured peripherals */
  MX_USB_DEVICE_Init();
  MX_TIM3_Init();
  MX_TIM6_Init();
  MX_TIM7_Init();
  MX_TIM10_Init();
  MX_FATFS_Init();
  MX_USB_HOST_Init();
  MX_I2C1_Init();
  MX_TIM2_Init();
  /* USER CODE BEGIN 2 */

  jumpToDFU = 0;

  // Check the OLED screen is there and initialize it if so
  screenOK = USB_Playback_Init();

  // Only start the input process timer if the screen has been detected
  if (screenOK) HAL_TIM_Base_Start_IT(&htim2);

  /* USER CODE END 2 */

  /* Infinite loop */
  /* USER CODE BEGIN WHILE */
  while (1)
  {
    /* USER CODE END WHILE */
    MX_USB_HOST_Process();

    /* USER CODE BEGIN 3 */
	  if(jumpToDFU == 1)
	  {
		  JumpToBootLoader();
	  }

	  // Only run USB playback task if screen has been detected
	  if (screenOK)
		  USB_Playback_Task();

  }
  /* USER CODE END 3 */
}

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
/* USER CODE BEGIN 4 */
void ReInitClockTimers(void)
{

	TIM_MasterConfigTypeDef sMasterConfig = {0};
	sMasterConfig.MasterOutputTrigger = TIM_TRGO_RESET;
	sMasterConfig.MasterSlaveMode = TIM_MASTERSLAVEMODE_DISABLE;

	// re-init tim6
	if (HAL_TIM_Base_Init(&htim6) != HAL_OK)
	{
		Error_Handler();
	}
	if (HAL_TIMEx_MasterConfigSynchronization(&htim6, &sMasterConfig) != HAL_OK)
	{
		Error_Handler();
	}

	// re-init tim7
	if (HAL_TIM_Base_Init(&htim7) != HAL_OK)
	{
		Error_Handler();
	}
	if (HAL_TIMEx_MasterConfigSynchronization(&htim7, &sMasterConfig) != HAL_OK)
	{
		Error_Handler();
	}

}

// Many thanks to Tien Majerle, owner of https://stm32f4-discovery.net/, for help with this function
void JumpToBootLoader(void) {
	void (*SysMemBootJump)(void);

	// De-init USB
	MX_USB_DEVICE_DeInit();
	MX_USB_HOST_DeInit();

	// Disable all of our interrupts (except systick which will be handled later)
	HAL_NVIC_DisableIRQ(EXTI0_IRQn);
	HAL_NVIC_DisableIRQ(EXTI1_IRQn);
	HAL_NVIC_DisableIRQ(EXTI4_IRQn);
	HAL_NVIC_DisableIRQ(EXTI9_5_IRQn);
	HAL_NVIC_DisableIRQ(OTG_FS_IRQn);
	HAL_NVIC_DisableIRQ(TIM3_IRQn);
	HAL_NVIC_DisableIRQ(TIM6_DAC_IRQn);
	HAL_NVIC_DisableIRQ(TIM7_IRQn);
	HAL_NVIC_DisableIRQ(TIM1_UP_TIM10_IRQn);
	HAL_NVIC_DisableIRQ(SysTick_IRQn);

	// De-init timers
	HAL_TIM_Base_DeInit(&htim3);
	HAL_TIM_Base_DeInit(&htim6);
	HAL_TIM_Base_DeInit(&htim7);
	HAL_TIM_Base_DeInit(&htim10);

	// clear all interrupts
	while (HAL_NVIC_GetPendingIRQ(EXTI0_IRQn))
	{
		__HAL_GPIO_EXTI_CLEAR_IT(P1_CLOCK_Pin);
		HAL_NVIC_ClearPendingIRQ(EXTI0_IRQn);
	}
	while (HAL_NVIC_GetPendingIRQ(EXTI1_IRQn))
	{
		__HAL_GPIO_EXTI_CLEAR_IT(P1_LATCH_Pin);
		HAL_NVIC_ClearPendingIRQ(EXTI1_IRQn);
	}
	while (HAL_NVIC_GetPendingIRQ(EXTI4_IRQn))
	{
		__HAL_GPIO_EXTI_CLEAR_IT(P1_DATA_2_Pin);
		HAL_NVIC_ClearPendingIRQ(EXTI4_IRQn);
	}
	while (HAL_NVIC_GetPendingIRQ(EXTI9_5_IRQn))
	{
		__HAL_GPIO_EXTI_CLEAR_IT(P2_CLOCK_Pin);
		__HAL_GPIO_EXTI_CLEAR_IT(P2_DATA_2_Pin);
		HAL_NVIC_ClearPendingIRQ(EXTI9_5_IRQn);
	}
	while (HAL_NVIC_GetPendingIRQ(TIM3_IRQn))
	{
		HAL_NVIC_ClearPendingIRQ(TIM3_IRQn);
	}
	while (HAL_NVIC_GetPendingIRQ(TIM6_DAC_IRQn))
	{
		HAL_NVIC_ClearPendingIRQ(TIM6_DAC_IRQn);
	}
	while (HAL_NVIC_GetPendingIRQ(TIM7_IRQn))
	{
		HAL_NVIC_ClearPendingIRQ(TIM7_IRQn);
	}
	while (HAL_NVIC_GetPendingIRQ(TIM7_IRQn))
	{
		HAL_NVIC_ClearPendingIRQ(TIM7_IRQn);
	}
	while (HAL_NVIC_GetPendingIRQ(TIM1_UP_TIM10_IRQn))
	{
		HAL_NVIC_ClearPendingIRQ(TIM1_UP_TIM10_IRQn);
	}
	while (HAL_NVIC_GetPendingIRQ(OTG_FS_IRQn))
	{
		HAL_NVIC_ClearPendingIRQ(OTG_FS_IRQn);
	}

	// Prepare to jump
	volatile uint32_t addr = 0x1FFF0000;

	// Restore VTOR
	SCB->VTOR = 0x08000000UL; /* Vector Table Relocation in Internal FLASH */

	// reset RCC back to default values
	HAL_RCC_DeInit();

	// clear SysTick
	SysTick->CTRL = 0;
	SysTick->LOAD = 0;
	SysTick->VAL = 0;

	// remaps the address of the system memory to 0x00000000
	// necessary for proper transition to bootloader
	SYSCFG->MEMRMP = 0x01;

	// sets destination address of the jump. note it is one word into the bootloader code which is the first instruction
	SysMemBootJump = (void (*)(void)) (*((uint32_t *)(addr + 4)));

	// sets the stack poitner to the first word of the bootloader code
	__set_MSP(*(uint32_t *)addr);

	// jump!
	SysMemBootJump();
}

/* USER CODE END 4 */
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


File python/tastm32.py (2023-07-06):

#!/usr/bin/env python3
import sys
import os
import serial
import struct
import time
import gc

import serial_helper
import argparse_helper

import r08, r16m, m64, dtm, rgen

DEBUG = False

int_buffer = 1024 # internal buffer size on replay device

latches_per_bulk_command = 28
packets = 4

VALID_PLAYERS = {
    "n64": (1,5,),
    "snes": (1,2,3,4,5,6,7,8,),
    "nes": (1,5,),
    "gc": (1,),
    "genesis": (1,5,)
}

int_to_byte_struct = struct.Struct('B')
def int_to_byte(interger):
    return int_to_byte_struct.pack(interger)

class TAStm32():
    def __init__(self, ser):
        att = 0
        while att < 5:
            try:
                self.ser = serial.Serial(ser, 115200, timeout=0.1)
                break
            except serial.SerialException:
                att += 1
                self.ser = None
                continue
        if self.ser == None:
            print ('ERROR: the specified interface (' + ser + ') is in use')
            sys.exit(0)
        else:
            self.activeRuns = {b'A': False, b'B': False, b'C': False, b'D': False}
            self.latchTrains = {b'A': None, b'B': None, b'C': None, b'D': None}

    def get_run_prefix(self):
        if self.activeRuns[b'A']:
            if self.activeRuns[b'B']:
                if self.activeRuns[b'C']:
                    if self.activeRuns[b'D']:
                        return None
                    else:
                        self.activeRuns[b'D'] = True
                        return b'D'
                else:
                    self.activeRuns[b'C'] = True
                    return b'C'
            else:
                self.activeRuns[b'B'] = True
                return b'B'
        else:
            self.activeRuns[b'A'] = True
            return b'A'

    def write(self, data):
        count = self.ser.write(data)
        if DEBUG and data != b'':
            print('S:', data)
        return count

    def read(self, count):
        data = self.ser.read(count)
        if DEBUG and data != b'':
            print('R:', data)
        return data

    def reset(self):
        c = self.read(1)
        if c == '':
            pass
        else:
            numBytes = self.ser.inWaiting()
            if numBytes > 0:
                c += self.read(numBytes)
        self.write(b'R')
        time.sleep(0.1)
        data = self.read(2)
        if data == b'\x01R':
            return True
        else:
            raise RuntimeError('Error during reset')

    def enable_controller(self):
        self.write(b'V1')

    def disable_controller(self):
        self.write(b'V0')

    def enable_relay(self):
        self.write(b'r1')

    def disable_relay(self):
        self.write(b'r0')

    def power_on(self):
        self.write(b'P1')

    def power_off(self):
        self.write(b'P0')

    def power_soft_reset(self):
        self.write(b'PS')

    def power_hard_reset(self):
        self.write(b'PH')

    def ping(self):
        self.write(b'\xAA')

    def waitForPong(self):
        readCount = 0
        start = time.time()
        while True:
            try:
                if time.time() > start+15:
                    return -1
                c = self.read(1)
                if c == '':
                    continue
                readCount += 1
                if c == b'\x55':
                    return 0
                if readCount > 1000:
                    return -2
            except serial.SerialException:
                return -3
            except KeyboardInterrupt:
                return -4

    def set_bulk_data_mode(self, prefix, mode):
        command = b''.join([b'Q', prefix, mode])
        self.write(command)

    def send_transition(self, prefix, frame, mode):
        if self.activeRuns[prefix]:
            command = ''
            if mode == b'N':
                # Set Normal Mode
                command = b''.join([b'T', prefix, mode, struct.pack('I', frame)])
            elif mode == b'A':
                # Set ACE Mode
                command = b''.join([b'T', prefix, mode, struct.pack('I', frame)])
            elif mode == b'S':
                # Set Soft Reset
                command = b''.join([b'T', prefix, mode, struct.pack('I', frame)])
            elif mode == b'H':
                # Set Hard Reset
                command = b''.join([b'T', prefix, mode, struct.pack('I', frame)])
            elif mode == b'R':
                # Wait for next rumble
                command = b''.join([b'T', prefix, mode, struct.pack('I', frame)])
            if command != '':
                self.write(command)

    def send_latchtrain(self, prefix, latchtrain):
        if self.activeRuns[prefix]:
            command = b''.join([b'U', prefix, struct.pack('H', len(latchtrain)), *[struct.pack('H', i) for i in latchtrain]])
            self.write(command)
            self.latchTrains[prefix] = latchtrain
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

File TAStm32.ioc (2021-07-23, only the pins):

Mcu.UserName=STM32F446RETx
PA0-WKUP.GPIO_Label=P1_DATA_3
PA0-WKUP.Signal=GPIO_Output
PA1.GPIO_Label=P1_DATA_2_OUT
PA1.Signal=GPIO_Input
PA10.GPIO_Label=PA10
PA10.Signal=GPIO_Input
PA11.Signal=USB_OTG_FS_DM
PA12.Signal=USB_OTG_FS_DP
PA13.GPIO_Label=TMS
PA13.Signal=SYS_JTMS-SWDIO
PA14.GPIO_Label=TCK
PA14.Signal=SYS_JTCK-SWCLK
PA15.GPIO_Label=V2_CLOCK
PA15.Signal=GPIO_Output
PA2.GPIO_Label=DIR_D0D1
PA2.Signal=GPIO_Output
PA3.GPIO_Label=PA3
PA3.Signal=GPIO_Input
PA4.GPIO_Label=DIR_P1D2D3
PA4.Signal=GPIO_Output
PA5.GPIO_Label=ENABLE_D0D1
PA5.Signal=GPIO_Output
PA6.GPIO_Label=ENABLE_P1D2D3
PA6.Signal=GPIO_Output
PA7.GPIO_Label=ENABLE_P2D2D3
PA7.Signal=GPIO_Output
PA8.GPIO_Label=PA8
PA8.Signal=GPIO_Input
PA9.GPIO_Label=SNES_RESET
PA9.Signal=GPIO_Output
PB0.GPIO_Label=DIR_P2D2D3
PB0.Signal=GPIO_Output
PB1.GPIO_Label=P2_DATA_3
PB1.Signal=GPIO_Output
PB10.GPIO_Label=P2_DATA_2_OUT
PB10.Signal=GPIO_Output
PB12.GPIO_Label=PB12
PB12.Signal=GPIO_Input
PB13.GPIO_Label=PB13
PB13.Signal=GPIO_Input
PB14.Signal=USB_OTG_HS_DM
PB15.Signal=USB_OTG_HS_DP
PB3.GPIO_Label=V1_DATA_2
PB3.Signal=GPIO_Output
PB4.GPIO_Label=V1_CLOCK
PB4.Signal=GPIO_Output
PB5.GPIO_Label=V1_LATCH
PB5.Signal=GPIO_Output
PB6.GPIO_Label=V1_DATA_1
PB6.Signal=GPIO_Output
PB7.GPIO_Label=V1_DATA_0
PB7.Signal=GPIO_Output
PB8.Signal=I2C1_SCL
PB9.Signal=I2C1_SDA
PC0.GPIO_Label=P1_CLOCK
PC0.Signal=GPXTI0
PC1.GPIO_Label=P1_LATCH
PC1.Signal=GPXTI1
PC10.GPIO_Label=V2_LATCH
PC10.Signal=GPIO_Output
PC11.GPIO_Label=V2_DATA_1
PC11.Signal=GPIO_Output
PC12.GPIO_Label=V2_DATA_0
PC12.Signal=GPIO_Output
PC13.GPIO_Label=PC13
PC13.Signal=GPIO_Input
PC14-OSC32_IN.GPIO_Label=PC14
PC14-OSC32_IN.Signal=GPIO_Input
PC15-OSC32_OUT.GPIO_Label=PC15
PC15-OSC32_OUT.Signal=GPIO_Output
PC2.GPIO_Label=P1_DATA_1
PC2.Signal=GPIO_Input
PC3.GPIO_Label=P1_DATA_0
PC3.Signal=GPIO_Input
PC4.GPIO_Label=P1_DATA_2
PC4.Signal=GPXTI4
PC5.GPIO_Label=P2_CLOCK
PC5.Signal=GPXTI5
PC6.GPIO_Label=P2_LATCH
PC6.Signal=GPIO_Input
PC7.GPIO_Label=P2_DATA_1
PC7.Signal=GPIO_Input
PC8.GPIO_Label=P2_DATA_0
PC8.Signal=GPIO_Input
PC9.GPIO_Label=P2_DATA_2
PC9.Signal=GPIO_Input
PD2.GPIO_Label=V2_DATA_3
PD2.Signal=GPIO_Output
PH0-OSC_IN.Signal=RCC_OSC_IN
PH1-OSC_OUT.Signal=RCC_OSC_OUT

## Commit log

2019-01-13 Project generated by STM32CubeMX
2019-01-15 Fixed serial driver and began communication framework
    [TAStm32.ioc, main.c, main.h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]
2019-01-16 more debug information on serial comunication and change to latch flow
2019-01-16 add blank frame command
2019-01-16 several bugs fixed with serial protocol
    [TASRun.c, TASRun.h, main.c]
2019-01-16 changed n64 data storage and serialization; fixed buffer size on python script
    [TASRun.c, main.c, n64.c]
2019-01-17 Update python to react to error codes sent from device
2019-01-18 custom usb device descriptor
2019-01-22 fix serial timeout and serial write
    [tastm32.py]
2019-01-22 fix buffer overflow detection and actually send a reset command
    [tastm32.py]
2019-01-23 fixed bugs for all 3 consoles!
    [TASRun.c, TAStm32.ioc, main.c]
2019-01-24 fixed timer; more complex games like SMB3 still do not work
    [main.c]
2019-01-25 DPCM fix works! SMB3 works!
    [TASRun.c, TASRun.h, main.c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]
2019-01-25 fixed off by one frame issue on first run
2019-01-25 fix crash on input length less than buffer size
    [tastm32.py]
2019-01-25 fix off by 1 in players arg
    [tastm32.py]
2019-01-26 fixed two script bugs
    [m64.py, tastm32.py]
2019-01-26 Fix Debug and n64 header
    [m64.py, tastm32.py]
2019-01-26 Fix Serial Auto Select
    [serial_helper.py]
2019-01-28 p2d0 does not work; other data lines appear OK
    [TASRun.c, TASRun.h]
2019-01-28 added basic dpcm fix and overread support over serial
    [TASRun.c, TASRun.h]
2019-01-29 fix transition arg type
    [tastm32.py]
2019-01-29 more fixes for transitions
    [tastm32.py]
2019-01-29 fix main loop end on end of input
    [tastm32.py]
2019-01-29 add dpcm fix to snes mode
    [tastm32.py]
2019-01-31 added DPCM transition code; fixed priorities; changed pins
    [TASRun.c, TASRun.h, TAStm32.ioc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]
2019-01-31 fixed bug and reduced output
    [tastm32.py]
2019-02-01 attempting switching implementation to @tewtal method; not working yet
    [TASRun.c, TASRun.h, main.c]
2019-02-01 Fix Include in Src/stm32f4xx_it.c
2019-02-02 added clock filter; SMB3 ACE payloads work consistently!
2019-02-03 added support for clock filter toggle through serial protocol
2019-02-03 add support for clock filter
2019-02-03 fix window mode being disabled
    [tastm32.py]
2019-02-03 improved clock fix check speed; lowered default clock timer from 5us to 4us
    [main.c]
2019-02-04 added customizable clock filter fix
    [TASRun.c, TAStm32.ioc, argparse_helper.py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]
2019-02-04 switch player index to 1 based, also fix multiple controllers for nes
    [r08.py, r16m.py, tastm32.py]
2019-02-04 small python NES players bug fix and C clock logic fix
    [TASRun.c, tastm32.py]
2019-02-07 updated pin mappings & small fixes
    [TAStm32.ioc, main.c, main.h]
2019-02-08 adding initial PCB design
    [TAStm32.brd, TAStm32.sch]
2019-02-18 updated PCBs to v1
    [TAStm32.brd, TAStm32.sch]
2019-02-21 a miriad of fixes and adjustments; console resets partially functional
    [TASRun.c, TASRun.h, TAStm32.ioc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]
2019-02-23 improved high data rate, misc logic fixes, increased serial baud rate
    [TASRun.h, main.c, tastm32-stream-snes-stereo.py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]
2019-02-23 sends 28 frames at a time when requested
2019-02-23 tiny bug fix involving non-existant variable
    [tastm32-stream-snes-stereo.py]
2019-03-14 added PCBs v2; new pin mappings and other improvements
    [TAStm32_v2.brd, TAStm32_v2.sch]
2019-03-22 works with new pin assignments
    [TAStm32.brd, TAStm32.sch, TAStm32_v2.brd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]
2019-03-22 migrated to latest STM32F4 firmware version
2019-04-06 attempting vis board code
2019-04-07 fixed NES power-on glitch
2019-04-08 more nes power fixes, better vis code which needs testing
    [main.c]
2019-04-09 added special fix for NES using vis boards
2019-04-11 more nes tweaks and major vis board changes
2019-04-15 switched data lanes from PP to OD with pullup
2019-04-22 Added 3D case and updated README
    [Case_bottom.stl, Case_top.stl, TAStm32.brd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]
2019-04-23 added case images
2019-04-24 more V2 fixes; P2_D2 changed to open-drain to match other data pins
    [TAStm32.ioc, main.c]
2019-04-25 improved P1D2 pin setup
2019-04-28 eliminated a potential race condition that rarely interfered with high datarate payload
    [TASRun.c]
2019-04-29 added new command to jump to DFU bootloader without using the hardware switch
2019-05-07 script to put device in DFU mode
2019-05-26 fixed and confirmed functionality of reset pins/commands
    [TAStm32.ioc, main.c]
2019-05-30 changed reset pin to work when connected directly to SNES reset; no need for transistor hardware intermediate
    [TAStm32.ioc, main.c, tastm32.py]
2019-07-04 adding drivers that were not tracked for some reason
2019-07-04 Fix Random "Error during reset" messages Fixes #10
    [tastm32.py]
2019-07-04 fix bit order for dtm loader
    [dtm.py]
2019-07-06 fixed windows serial issues (baud rate). fixed .dtm to be one-to-one to match new dolphin build
    [dtm.py, tastm32.py]
2019-07-07 fixed one tiny NES logic error and one tiny GC logic error
    [n64.c]
2019-07-18 updated case files to include window for reset pins
    [Case_bottom.stl, Case_top.stl]
2019-11-11 Fixed N64/GC protocol logic error requiring a blank frame be prepended to sync
    [dtm.py]
2019-11-16 port to firmware 1.24, fixed untracked files, and .gitignore modifications
    [TAStm32.ioc, main.c]
2019-11-17 remove unused button, Add USART2 boilerplate code
2019-11-17 Remove hardcoded pin/port references for GCN mode
2019-11-18 removed some volatiles and fixed extern declarations
    [main.c, serial_interface.c]
2019-11-18 transitioning away from UART2 HAL. not yet working
2019-11-18 more work; still not working
    [main.c]
2019-11-19 UART2 works somewhat, and still slowly
2019-11-23 fixed NULL pointers and added more correct references
    [serial_interface.c]
2019-11-23 switching to serial_interface function call
2019-11-23 Trying to make the input frame transfer faster
2019-11-23 fix USART2 communication IT. attempt 2M baud rate
    [main.c, tastm32.py]
2019-11-24 rolled back baud to 115200. corrected transition logic
    [main.c, serial_interface.c, tastm32.py]
2019-12-29 whoops fixed timer configuration
    [TAStm32.ioc, main.c]
2019-12-30 reduce print clutter during run init
2020-01-01 fixed latch train bugs/logic
    [serial_interface.c, tastm32.py]
2020-01-06 Fixed overwriting arbitrary memory
    [serial_interface.c]
2020-01-06 fixed not (re-)initializing latch_train_index to 0
    [serial_interface.c]
2020-01-09 Fix bug with --players arg Fix bug with n64 player selection
    [argparse_helper.py, tastm32.py]
2020-01-12 Initial pass-through for some light cleanup (#21)
    * Remove duplicate syscalls.c; the one in Src/ is more visible
    * Add a Makefile; builds on FreeBSD w/ arm-none-eabi-gcc+newlib
    * stm32f4xx_it: move global variable declarations into header
    This makes it easier to keep declarations in sync across multiple
    compilation units; only the declaration here in the header and the
    definition in a *.c exists, and any conflict between the two will be
    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
2020-01-13 scripts return 1 in event of latch train failure to notify calling process
    [tastm32.py]
2020-01-21 Switch Makefile build to C11
    This was previously set to C99, but that's technically too restrictive- the
    standard builds done via TrueSTUDIO will be C11+GNU, so let's aim to support
    base C11 with no extensions.
2020-02-11 separate pin writes for increased stability
2020-02-17 Fix location of reset argument handler
    [tastm32.py]
2020-03-14 Inverted reset pin logic
2020-03-27 fixed transition bug fix introduced a few months ago; re-organized some code
    [serial_interface.c, tastm32.py]
2020-03-28 Remove unnecessary volatiles, track compiled binary, remove possible sleep side effects (#26)
    * removed many unnecessary volatiles
    * ensure asm wait has no register side effects
    * tracking binary
2020-05-01 Added v3 PCB and case files
    [TAStm32 v3 Bottom Case.stl, TAStm32 v3 Top Case.stl, TAStm32_v3.brd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]
2020-05-02 more case v3 tweaks
    [TAStm32 v3 Bottom Case.stl]
2020-05-02 testing optimized vis board code (#27)
2020-05-02 Cleanup (#28)
    * various proposed improvements in style and logic
    * fixed relative paths in update.bat
    [TASRun.c, serial_interface.c]
2020-05-03 fixed latch/clock timer issues and latch train issue
    [TAStm32.ioc, main.c, tastm32.py]
2020-05-25 Fix Help Text on movie file parsers
    [dtm.py, m64.py, r08.py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]
2020-05-25 Disable Printing Header when loading input data
2020-05-26 Add Support for GMV (Genesis) movies (3 and 6 button)
2020-06-04 Dev/gmvfix (#29)
    Fixed erroneous code in genesis handler.
    [tastm32.py]
2020-07-05 Re-haul OD to PP; random data fix; DFU bug fix (#30)
    * fixed random data on unused data lines
    * increased time of DFU update from 1 to 2 seconds
    * timer10 cleanup when jumping to DFU
    * start with interrupts disabled
    [TASRun.c, main.c, serial_interface.c]
2020-08-24 fixed capacitor C7 value
    [TAStm32_v3.brd, TAStm32_v3.sch]
2020-08-24 removed old versions of PCB and case to reduce confusion
    [Case_bottom.stl, Case_top.stl, TAStm32.brd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]
2020-09-11 GC/N64: Fix controller bit ordering with SendByte (#33)
    [n64.c]
2020-09-23 Multiple new features and fixes
    - Playback from USB filesystem
    - SNES multitap support
    - High impedance data lines on startup until first latch
    - Misc. optimizations and cleanup
    [TASRun.c, TASRun.h, TAStm32.ioc]
2020-10-14 fixed reset pin driving bug
    [main.c]
2021-01-15 software filter to overcome hardware latch issues
2021-01-24 Revert "software filter to overcome hardware latch issues"
    This reverts commit 452d4531b21aadb9f9148dcc4f272866f228dda8.
2021-01-27 restore snes reset pin to open-drain for proper NES/SNES functionality
2021-01-29 add file with rj45 pin numbers
2021-02-28 N64 2p support
    * 2p N64 and GCN support
    * prefix gc and n64 functions, inspired by @sauraen
    * update GCN64_ReadCommand
    * python n64 2p fixes
    * added bulk transfer stuff for n64
    * untrack binary and truestudio settings
    [TASRun.c, TASRun.h, m64.py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]
2021-06-02 "wait for next rumble" transition / melee poll alarm bug mitigation (#55)
    [TASRun.c, TASRun.h, argparse_helper.py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]
2021-07-08 Merge controller-test branch (#58)
    New features:
    script for controlling console with xbox controller(s). uses N64 as an example
    script for controlling console with midi device. uses n64 and drumset as an example
    the two aforementioned features use the new "controller" mode, which does not buffer inputs
    reset pins can now use push-pull or open-drain as appropriate
    n64 mode is now properly open-drain
2021-07-23 TAStm32 v4 with backwards compatibility and many improvements (#57)
    Including but not limited to:
    * v4 board support
    - increased signal integrity, protection diodes, small LCD display, and more!
    * Code cleanups
    * Interrupt table and routines in ram for increased performance
    [TAStm32 v4r2 Bottom Case.stl, TAStm32 v4r2 Top Case.stl, TAStm32_v4.brd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]
2021-09-19 write blank frames at end of run instead of not replying
2021-11-20 USB playback interrupt init bugfix
    [usbplayback.c]
2022-07-14 remove psutil import
    no longer used
    [tastm32.py]
2023-05-26 fixed vis board functionality
    [TASRun.c]
2023-06-09 fix tolerance and E1 vs E2 position
    [TAStm32 v4r2 Bottom Case.stl, TAStm32 v4r2 Top Case.stl]
2023-07-06 Reset init fix (#64)
    * fix reset pin initial state
    * add relay mode to on/off scripts
    ---------
    [TASRun.c, argparse_helper.py]
2023-07-06 Fix/latch train logic and minor fixes (#63)
    * Add .vscode to .gitignore
    * Add script to reset TAStm32 device
    * Change Command for Controller Mode to V from C
    fixes #61
    * Make latchtrain messages more verbose
    * Update tastm32.py to match protocol change for controller mode
    * update midi-n64 script with protocol conflict resolution
    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
    [dtm_converter.py, serial_interface.c, tastm32-controller.py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]
2023-07-07 latch train failure no longer repeats frame
2023-07-10 Pause command for GCN/N64 (#65)
    * added p0 and p1 command to unpause and pause replay
    * dont send latch message when puased
    * fixed serial handler softlock
    * added ability to skip a poll
    * fix some serial state settings
    [TASRun.h, serial_interface.c]
2024-01-08 analog directions based on velocity
2025-11-01 changed GPIOA mask to not affect the reset pin
2026-07-04 fix: Update Makefile to limit DFU device to STM32 serial (#71)

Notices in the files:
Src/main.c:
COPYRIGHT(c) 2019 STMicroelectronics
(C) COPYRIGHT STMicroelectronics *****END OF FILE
